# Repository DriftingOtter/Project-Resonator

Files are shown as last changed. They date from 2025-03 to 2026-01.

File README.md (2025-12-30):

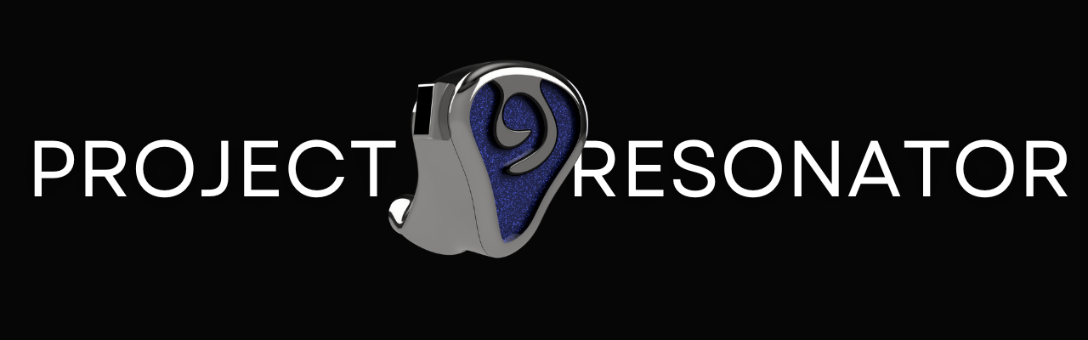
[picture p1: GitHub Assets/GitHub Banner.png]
Banner


# Project Resonator | *The* Open-Source IEM Initiative
> A love letter to the IEM/CIEM hobby.

**📖 Documentation Website:** [https://driftingotter.github.io/Project-Resonator-Web/](https://driftingotter.github.io/Project-Resonator-Web/)

---

## What is Project Resonator?

Project Resonator is a comprehensive knowledge base and resource repository for the complete design cycle and engineering development of in-ear monitors (IEMs). The project aims to bridge the gap between hobbyist curiosity and professional-grade IEM development by providing both the technical resources and educational foundation needed to understand and create high-fidelity audio devices.

### Core Resources

Project Resonator provides a complete suite of engineering resources:

- **CAD Shell Design Files** — Parametric 3D models for ergonomic IEM housings
- **Crossover Simulation Circuits** — Fully documented acoustic crossover networks in VituixCAD
- **PCB Design Files** — Production-ready circuit board layouts in KiCad format
- **Driver Characterization Data** — Frequency response and impedance measurements for balanced armature, dynamic, and electrostatic drivers

These resources are designed for both DIY enthusiasts exploring personal audio projects and aspiring entrepreneurs researching entry into the IEM market who may lack formal training in acoustics or electrical engineering.

### Educational Framework

Beyond physical assets, Project Resonator's primary value lies in its structured tutorial system that demystifies each stage of IEM development:

- **Driver Technology & Selection** — Understanding the physics and performance characteristics of transducer types
- **Crossover Circuit Design** — Acoustic filter theory and frequency division network topology
- **PCB Engineering in KiCad** — Translating schematic designs into manufacturable circuit boards
- **CAD Modeling for Acoustics** — Shell geometry, acoustic chambers, and sound bore design in Fusion 360

By consolidating these resources into a single, cohesive repository, Project Resonator enables users to understand the technology they use daily and provides a foundation for experimentation, innovation, and research & development in personal audio.

### Open-Source Collaboration

The open-source nature of this project allows the community to contribute to a centralized knowledge base, helping others in the same pursuit by:

- Improving and expanding existing documentation
- Contributing additional design files and measurement data
- Sharing novel tuning approaches and manufacturing techniques
- Building supplementary tools and resources for IEM development

Project Resonator serves as a living resource that evolves with the IEM community, fostering innovation through shared knowledge and collaborative development.

---

## The Reference Design (Template)

While the guides apply to *any* IEM project, we provide a complete set of files for a specific "Reference" model to get you started.

**Configuration:** All-BA 4-Driver (1× Low + 1× Mid + 2× High)

**Drivers:**
- Knowles CI-22955 (Low)
- Knowles BK-26824 (Mid)
- Knowles SWFK-31736 (Highs)

**Target Tuning:** Similar to the *Moondrop x Crinacle DUSK*

**Estimated Build Cost:** ~$200-300

### Reference Crossover Diagram

```mermaid
graph LR
    Input[Source Input] --> Woofer_Path[Woofer Path<br/>CI-22955]
    Input --> Mid_Path[Mid Path<br/>BK-26824]
    Input --> High_Path[High Path<br/>SWFK-31736]
    
    Woofer_Path --> R1[22Ω Series]
    R1 --> C1[4.7µF Parallel]
    C1 --> Woofer[CI-22955<br/>BA Woofer]
    
    Mid_Path --> C2[10µF Series]
    C2 --> R2[22Ω Series]
    R2 --> C3[4.7µF Parallel]
    C3 --> Mids[BK-26824<br/>BA Mids]
    
    High_Path --> T1_Path[Tweeter 1]
    High_Path --> T2_Path[Tweeter 2]
    
    T1_Path --> C4[2.2µF Series]
    C4 --> R3[6.8Ω Parallel]
    R3 --> Tweeter1[SWFK-31736<br/>Unit A]
    
    T2_Path --> C5[2.2µF Series]
    C5 --> R4[22Ω Parallel]
    R4 --> Tweeter2[SWFK-31736<br/>Unit B]
    
    style Woofer fill:#1a1a1a
    style Mids fill:#1a1a1a
    style Tweeter1 fill:#1a1a1a
    style Tweeter2 fill:#1a1a1a
    style Input fill:#1a1a1a
```

**Note:** The reference tuning is highly individualized. The project's purpose is to provide all necessary tools and resources pre-configured, allowing you to use this as a foundation to tune and create an IEM tailored to your preferences.

---

## 🔧 Technologies Used & Software Required

1. **VituixCAD** — Tuning simulation and acoustic crossover design
2. **KiCad** — Schematic and PCB design
3. **Autodesk Fusion 360** — CAD modeling for IEM shells
4. **FPGraphTracer** — Extracting frequency and impedance responses from driver spec sheets

**Additional Resources:**
- [YouTube Playlist: IEM Building Resources](https://youtube.com/playlist?list=PL4ahDGGN5zBFhmGqVUoBdOnjuF_9HXV5L)
- [Full Documentation Website](https://driftingotter.github.io/Project-Resonator-Web/)

---

## 🛠️ Installation & Setup Guide

### VituixCAD Setup

1. Download VituixCAD from [https://kimmosaunisto.net/](https://kimmosaunisto.net/)
2. Install and open the `.vxp` simulation file included in this repository
3. **Fix missing file paths:**
   - You'll likely see "missing file path" errors on first load
   - Click the folder icon next to each `.frd` or `.zma` file slot
   - Navigate to the `BA Driver Spec Sheets` folder in this repo
   - Re-link the appropriate files for each driver

*(This only needs to be done once per project file)*

### Downloading IEM Shell Files

All IEM shell files are hosted externally on **MEGA** due to GitHub's file size limitations.

🔗 **[Download Shell Files from MEGA](https://mega.nz/folder/2Z4WzYDR#g-NULd1YQFsHa81YXLZzIw)**

The archive includes:
- **Ready-To-Print** — `.stl` files for direct 3D printing
- **Fusion-Shell-Models** — Editable `.f3d` files for customization in Fusion 360

---

## 📚 Documentation

Complete guides are available on the [Project Resonator Documentation Website](https://driftingotter.github.io/Project-Resonator-Web/), including:

### Engineering & Design
- [Driver Selection](https://driftingotter.github.io/Project-Resonator-Web/docs/Driver-Selection)
- [Crossover Design](https://driftingotter.github.io/Project-Resonator-Web/docs/Crossover-Design)
- [Crossover Tuning](https://driftingotter.github.io/Project-Resonator-Web/docs/Crossover-Tuning)
- [Component Picking](https://driftingotter.github.io/Project-Resonator-Web/docs/Component-Picking)

### Manufacturing & CAD
- [PCB Design](https://driftingotter.github.io/Project-Resonator-Web/docs/PCB-Design)
- [Shell Design](https://driftingotter.github.io/Project-Resonator-Web/docs/Shell-Design)
- [Shell Material and Manufacturing](https://driftingotter.github.io/Project-Resonator-Web/docs/Shell-Material-and-Manufacturing)

### Project Information
- [Tools & Software](https://driftingotter.github.io/Project-Resonator-Web/docs/Tools-&-Software)
- [Project Goals & Philosophy](https://driftingotter.github.io/Project-Resonator-Web/docs/Project-Goals-Philosophy)
- [Project Licensing and Usage](https://driftingotter.github.io/Project-Resonator-Web/docs/Project-Licensing-and-Usage)
- [FAQ & Troubleshooting](https://driftingotter.github.io/Project-Resonator-Web/docs/FAQ-Troubleshooting)
- [How to Contribute](https://driftingotter.github.io/Project-Resonator-Web/docs/Contribution)

---

## ❓ Can I Use These Files To Build My Own IEM?

**Absolutely.** This project is licensed under **CERN-OHL-W** (weakly reciprocal), which allows you to:

- Build IEMs for personal use
- Modify and improve the designs
- Use this as a foundation for commercial projects

The license maintains the open-source spirit while being permissive enough for commercial applications. For full details, see the [Project Licensing and Usage](https://driftingotter.github.io/Project-Resonator-Web/docs/Project-Licensing-and-Usage) documentation.

**Note:** This design represents a learning journey and is far from perfect—but it provides a solid foundation and realistic look at what an IEM build process entails. Use it as a starting point to avoid some of the mistakes made along the way.

---

## 🤝 Contributing

Project Resonator welcomes contributions from the community! Whether you're improving documentation, adding measurement data, sharing tuning variants, or fixing errors, your input helps everyone.

See the [Contribution Guide](https://driftingotter.github.io/Project-Resonator-Web/docs/Contribution) for details on how to get involved.

---

## 🚧 Current Status & Community Testing

**Important:** The reference design has not yet been physically tested by the project author due to budget constraints (~$300 build cost). If you build this design, your feedback and measurements would be invaluable to the community. Please share your results and listening impressions!

---

## 👨‍💻 Author

**Daksh Kaul** (DriftingOtter)

---

## 🙌 Credits & Acknowledgments

Special thanks to:

- **Head-Fi DIY IEM Community** — For fostering knowledge sharing and experimentation
- **[Kozh](https://www.youtube.com/@kozh4013/videos)** — IEM design tutorials and insights
- **[Kirby Meets Audio](https://youtu.be/QClvPIuW3zI)** — Driver selection and acoustic theory
- **[Crinacle](https://www.youtube.com/watch?v=tCqV3ZRcZ9g)** — Measurement methodology and target curves
- **[Mr.T's Design Graveyard](https://youtu.be/3FGNw28xBr0)** — PCB design techniques

*If I've forgotten to credit you, please reach out—contributions are always acknowledged.*

---

## 📄 License

This project is licensed under **CERN Open Hardware Licence Version 2 - Weakly Reciprocal** (CERN-OHL-W).

See [LICENSE](./LICENSE) or the [Project Licensing Documentation](https://driftingotter.github.io/Project-Resonator-Web/docs/Project-Licensing-and-Usage) for full details.

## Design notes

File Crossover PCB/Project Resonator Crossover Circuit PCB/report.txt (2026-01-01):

Warning: Width correction constrained.  The width correction value must be in the range of [0.000001 mm; -0.000002 mm] for the current design rules.
Warning: Width correction constrained.  The width correction value must be in the range of [0.000001 mm; -0.000002 mm] for the current design rules.
Plotted to '/Users/daksh/Documents/Project-Resonator/Crossover PCB/Project Resonator Crossover Circuit PCB/Project Resonator Crossover Circuit PCB/Project Resonator Crossover Circuit PCB-F_Cu.gbr'.
Plotted to '/Users/daksh/Documents/Project-Resonator/Crossover PCB/Project Resonator Crossover Circuit PCB/Project Resonator Crossover Circuit PCB/Project Resonator Crossover Circuit PCB-B_Cu.gbr'.
Plotted to '/Users/daksh/Documents/Project-Resonator/Crossover PCB/Project Resonator Crossover Circuit PCB/Project Resonator Crossover Circuit PCB/Project Resonator Crossover Circuit PCB-F_Paste.gbr'.
Plotted to '/Users/daksh/Documents/Project-Resonator/Crossover PCB/Project Resonator Crossover Circuit PCB/Project Resonator Crossover Circuit PCB/Project Resonator Crossover Circuit PCB-B_Paste.gbr'.
Plotted to '/Users/daksh/Documents/Project-Resonator/Crossover PCB/Project Resonator Crossover Circuit PCB/Project Resonator Crossover Circuit PCB/Project Resonator Crossover Circuit PCB-F_Silkscreen.gbr'.
Plotted to '/Users/daksh/Documents/Project-Resonator/Crossover PCB/Project Resonator Crossover Circuit PCB/Project Resonator Crossover Circuit PCB/Project Resonator Crossover Circuit PCB-B_Silkscreen.gbr'.
Plotted to '/Users/daksh/Documents/Project-Resonator/Crossover PCB/Project Resonator Crossover Circuit PCB/Project Resonator Crossover Circuit PCB/Project Resonator Crossover Circuit PCB-F_Mask.gbr'.
Plotted to '/Users/daksh/Documents/Project-Resonator/Crossover PCB/Project Resonator Crossover Circuit PCB/Project Resonator Crossover Circuit PCB/Project Resonator Crossover Circuit PCB-B_Mask.gbr'.
Plotted to '/Users/daksh/Documents/Project-Resonator/Crossover PCB/Project Resonator Crossover Circuit PCB/Project Resonator Crossover Circuit PCB/Project Resonator Crossover Circuit PCB-Edge_Cuts.gbr'.
Created Gerber job file '/Users/daksh/Documents/Project-Resonator/Crossover PCB/Project Resonator Crossover Circuit PCB/Project Resonator Crossover Circuit PCB/Project Resonator Crossover Circuit PCB-job.gbrjob'.
Info: Done.
Info: Done.

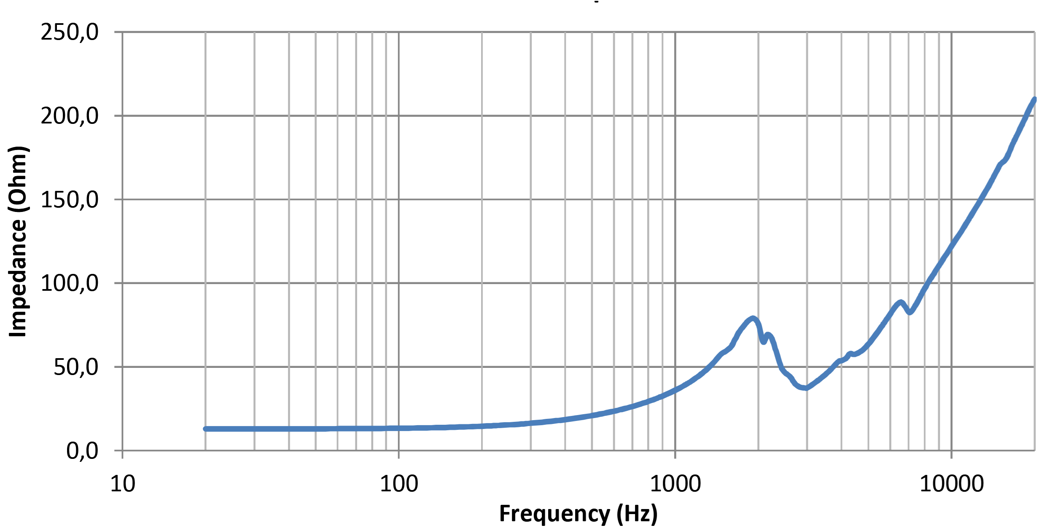
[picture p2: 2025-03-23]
BA Driver Spec Sheets/Knowles_ED_30262/Impedence_Response.png

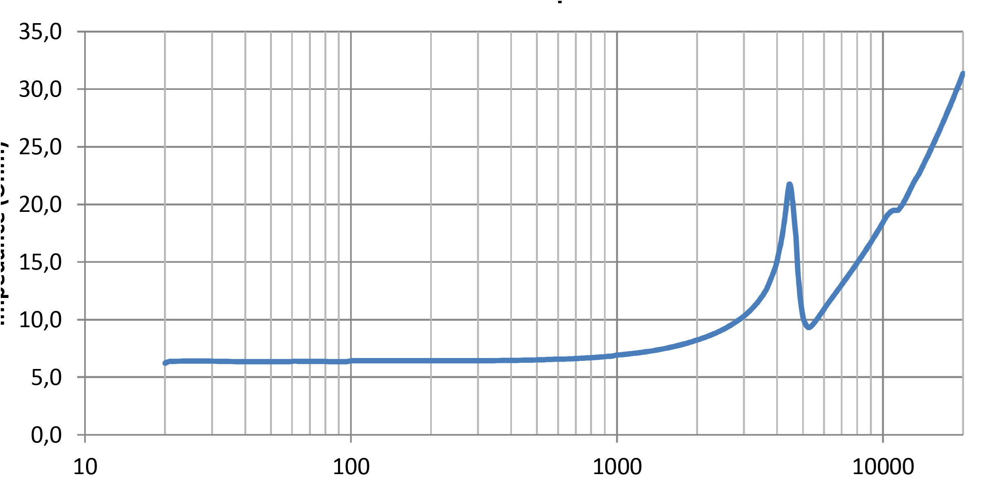
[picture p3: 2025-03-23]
BA Driver Spec Sheets/Knowles_SWFK_31736/Impedence_Response.png

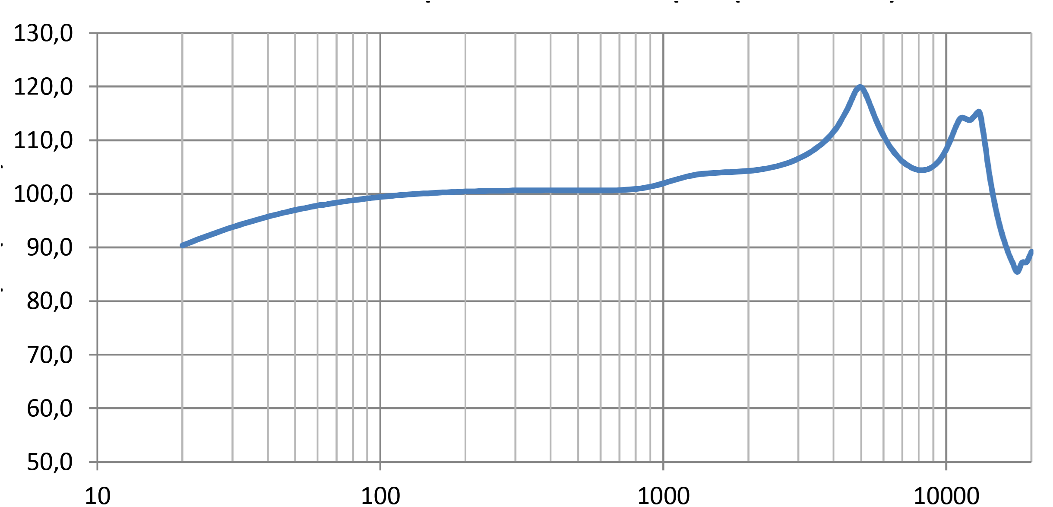
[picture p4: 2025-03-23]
BA Driver Spec Sheets/Knowles_SWFK_31736/Frequnecy_Response.png

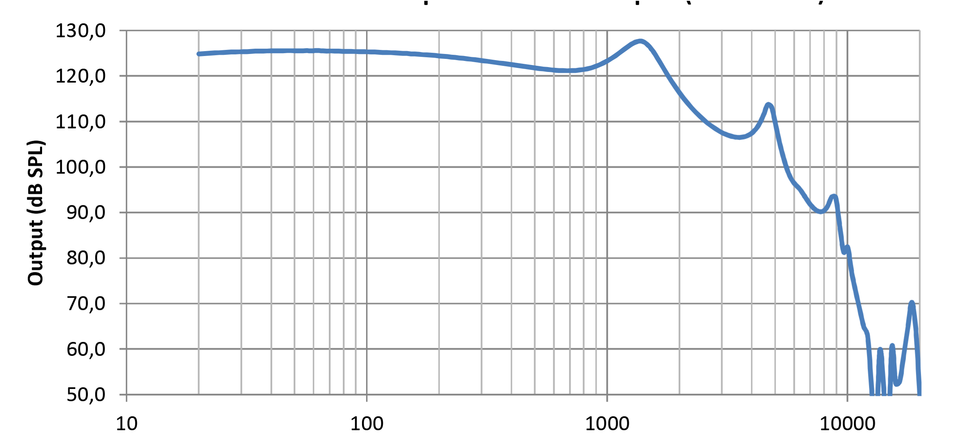
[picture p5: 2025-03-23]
BA Driver Spec Sheets/Knowles_HODVTEC-31618/Frequnecy_Response.png

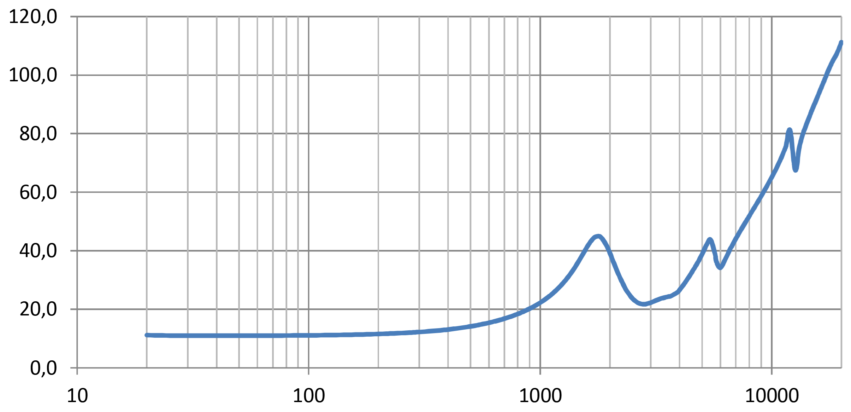
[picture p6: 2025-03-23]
BA Driver Spec Sheets/Knowles_BK_26824/Impedence_Response.png

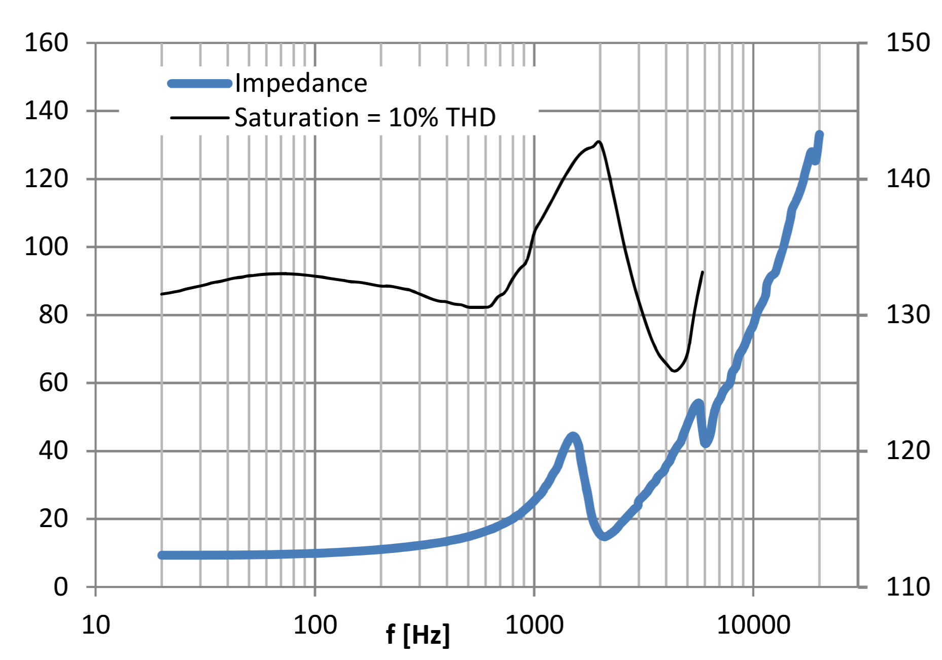
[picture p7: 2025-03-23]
BA Driver Spec Sheets/Knowles_RDI_34006/Impedence_Response.png

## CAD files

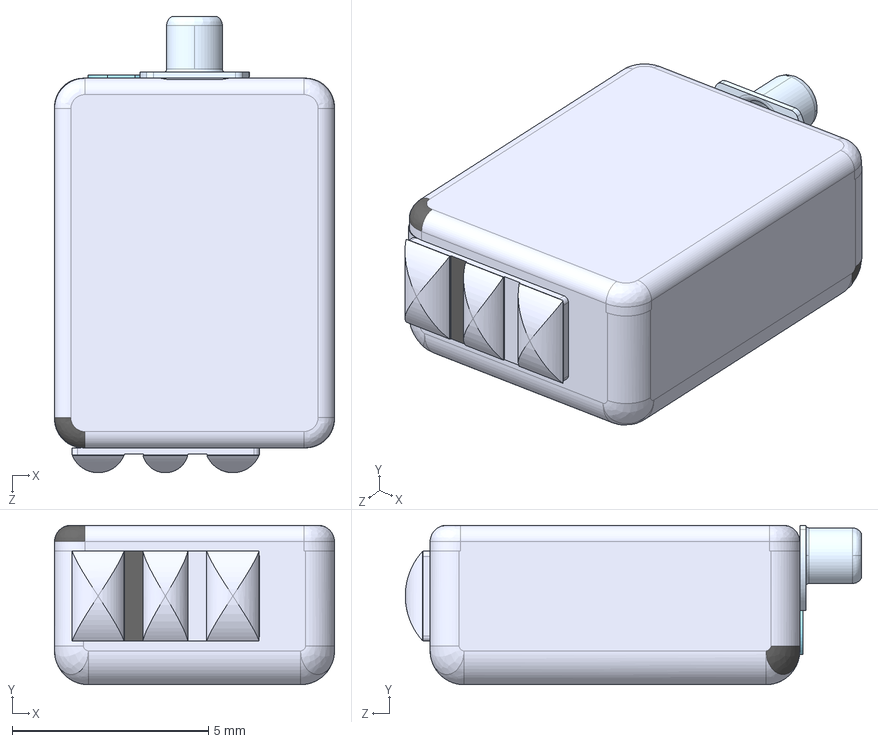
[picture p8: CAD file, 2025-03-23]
BA Driver Spec Sheets/Knowles_CI_22955/LIB_CI-22955-000/CI-22955-000/3D/CI-22955-000.stp
7.14 x 4.06 x 11.6 mm
ci-22955-000_sw1
ci-22955-000_sw2
ci-22955-000_sw3
ci-22955-000_sw4
ci-22955-000_sw5

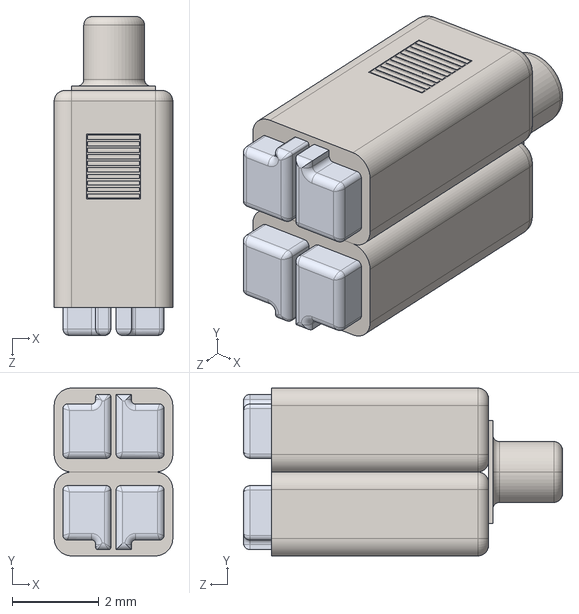
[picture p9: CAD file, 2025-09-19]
BA Driver Spec Sheets/Knowles_SWFK_31736/LIB_SWFK-31736-000/SWFK-31736-000/3D/SWFK-31736-000.stp
2.73 x 3.86 x 7.34 mm

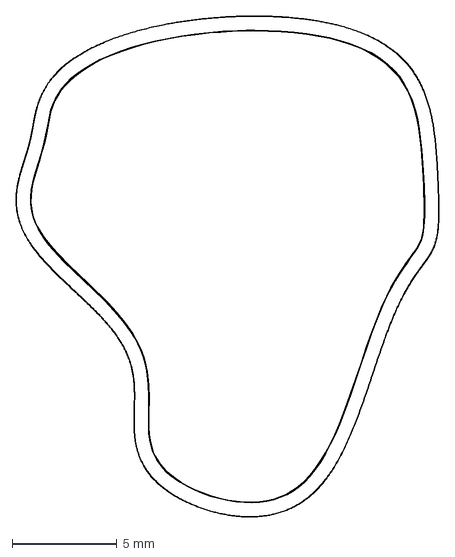
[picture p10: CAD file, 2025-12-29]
Crossover PCB/Entangler_TWS/Entangle_PCB_Outline.dxf
20.2 x 23.9 mm

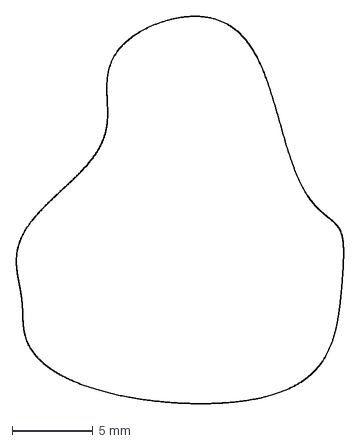
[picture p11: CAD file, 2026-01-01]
Crossover PCB/PCB OUTLINE.dxf
20.2 x 23.9 mm

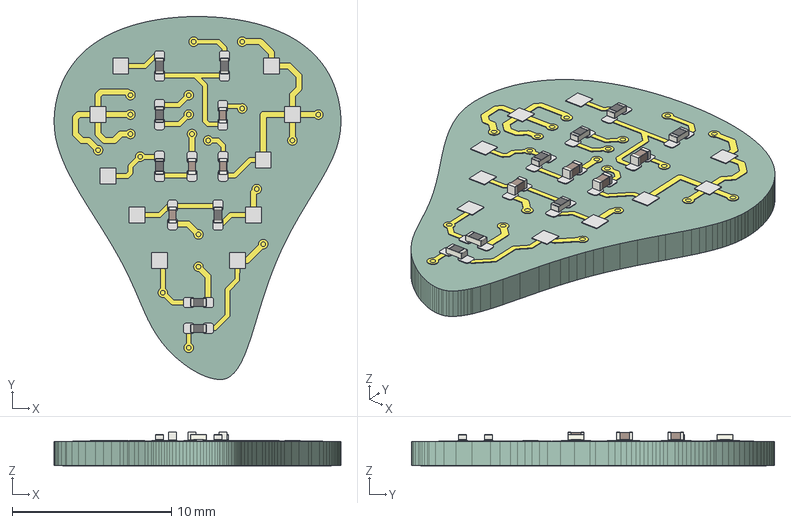
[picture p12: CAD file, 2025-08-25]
Crossover PCB/Project Resonator Crossover Circuit PCB.step
18.0 x 22.8 x 2.13 mm
R_0402_1005Metric x 7
C_0402_1005Metric x 4
Project Resonator Crossover Circuit PCB_copper
Project Resonator Crossover Circuit PCB_pad
Project Resonator Crossover Circuit PCB_via
Project Resonator Crossover Circuit PCB_PCB

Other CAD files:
BA Driver Spec Sheets/Knowles_SWFK_31736/LIB_SWFK-31736-000/SWFK-31736-000/3D/SWFK-31736-000.obj

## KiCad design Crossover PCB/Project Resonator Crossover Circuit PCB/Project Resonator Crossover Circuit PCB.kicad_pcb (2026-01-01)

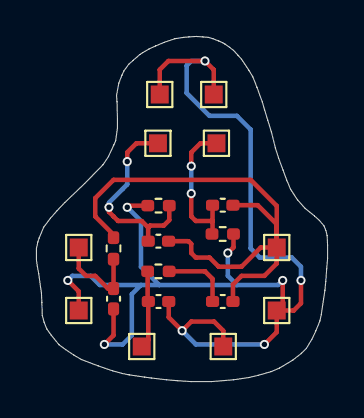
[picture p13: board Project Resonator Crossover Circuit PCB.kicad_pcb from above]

Board: 2 copper layers, 16.2 x 19.2 mm, 19 parts (0 on the bottom side), 2 nets.

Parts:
C1: 10uF; C_0402_1005Metric_Pad0.74x0.62mm_HandSolder
C2, C6: 2.2uF; C_0402_1005Metric_Pad0.74x0.62mm_HandSolder
C4: 0.10uF; C_0402_1005Metric_Pad0.74x0.62mm_HandSolder
C5: 4.7uF; C_0402_1005Metric_Pad0.74x0.62mm_HandSolder
H1: CI PAD (+); TestPoint_Pad_1.0x1.0mm
H2: CI PAD (-); TestPoint_Pad_1.0x1.0mm
H3: BK PAD (+); TestPoint_Pad_1.0x1.0mm
H4: BK PAD (-); TestPoint_Pad_1.0x1.0mm
H5: SWFK #1 PAD (+); TestPoint_Pad_1.0x1.0mm
H6: SWFK #1 PAD (-); TestPoint_Pad_1.0x1.0mm
H7: SWFK #2 PAD (+); TestPoint_Pad_1.0x1.0mm
H8: SWFK #2 PAD (-); TestPoint_Pad_1.0x1.0mm
H9: SOURCE PAD (+); TestPoint_Pad_1.0x1.0mm
H10: SOURCE PAD (-); TestPoint_Pad_1.0x1.0mm
R2, R5, R6: 22R; R_0402_1005Metric_Pad0.72x0.64mm_HandSolder
R3: 6.8R; R_0402_1005Metric_Pad0.72x0.64mm_HandSolder

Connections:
+: C1.1, C2.1, C2.2, C4.1, C4.2, C5.1, C6.1, C6.2, H1.1, H3.1, H5.1, H7.1, H9.1, R2.1, R2.2, R3.1, R5.1, R5.2, R6.1
GND: C1.2, C5.2, H2.1, H4.1, H6.1, H8.1, H10.1, R3.2, R6.2

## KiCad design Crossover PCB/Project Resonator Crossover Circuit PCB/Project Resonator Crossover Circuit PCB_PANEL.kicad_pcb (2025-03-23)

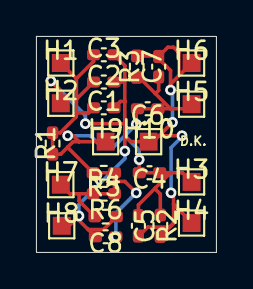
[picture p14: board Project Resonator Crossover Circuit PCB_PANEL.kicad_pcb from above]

Board: 2 copper layers, 10.0 x 12.0 mm, 24 parts (0 on the bottom side), 2 nets.

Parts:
C1, C2, C3: 100u; C_0402_1005Metric_Pad0.74x0.62mm_HandSolder
C4: 0.027u; C_0402_1005Metric_Pad0.74x0.62mm_HandSolder
C5: 4.7u; C_0402_1005Metric_Pad0.74x0.62mm_HandSolder
C6: 0.008u; C_0402_1005Metric_Pad0.74x0.62mm_HandSolder
C7: 2.2u; C_0402_1005Metric_Pad0.74x0.62mm_HandSolder
C8: 10u; C_0402_1005Metric_Pad0.74x0.62mm_HandSolder
H1, H3, H5, H7, H9: + MountingHole_Pad; TestPoint_Pad_1.0x1.0mm
H2, H4, H6, H8: - MountingHole_Pad; TestPoint_Pad_1.0x1.0mm
H10: MountingHole_Pad; TestPoint_Pad_1.0x1.0mm
R1: 5600R; R_0402_1005Metric_Pad0.72x0.64mm_HandSolder
R2: 22R; R_0402_1005Metric_Pad0.72x0.64mm_HandSolder
R3: 10000R; R_0402_1005Metric_Pad0.72x0.64mm_HandSolder
R4: 6800R; R_0402_1005Metric_Pad0.72x0.64mm_HandSolder
R5: 0.092R; R_0402_1005Metric_Pad0.72x0.64mm_HandSolder
R6: 6.8R; R_0402_1005Metric_Pad0.72x0.64mm_HandSolder

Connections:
+: C1.1, C2.1, C3.1, C4.1, C4.2, C5.1, C6.1, C6.2, C7.1, C8.1, H1.1, H3.1, H5.1, H7.1, H9.1, R1.1, R1.2, R2.1, R3.1, R4.1, R4.2, R5.1, R5.2, R6.1
GND: C1.2, C2.2, C3.2, C5.2, C7.2, C8.2, R2.2, R3.2, R6.2

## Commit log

2025-03-23 my passion project
    [CI-22955-000.stp, DigiKey_PCB_Components_Parts_List.csv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]
2025-03-23 removed software files, and old files not used for project
    [CI-22955-000.stp]
2025-03-23 Accdentally removed BA driver measurements
    [CI-22955-000.stp]
2025-03-27 modified crossover to use 2nd order low pass instead of high capacitance series chains
2025-04-04 MAJOR UPDATE: Improved Crossover to reduce redudent componets from 15 -> 10, Improved subbass isolation, updated PCB to reflect changes, added v3 shell images to assets, uploaded new gerber and drill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
    [Project Resonator Crossover Circuit PCB-B_Cu.gbr, Project Resonator Crossover Circuit PCB-B_Mask.gbr, Project Resonator Crossover Circuit PCB-B_Silkscreen.gbr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]
2025-04-04 Updated README to include Morten Arnoldus's measurements for Knowles BA drivers && included files to the BA drivers measurements directory
2025-04-04 Added the compressed Gerber and Drill Files of the new PCB overall
2025-04-04 updated PCB to connect ground pour to GND and make track size to 8mils and fixed clearence issues
    [Project Resonator Crossover Circuit PCB-B_Cu.gbr, Project Resonator Crossover Circuit PCB-B_Mask.gbr, Project Resonator Crossover Circuit PCB-B_Paste.gbr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]
2025-04-04 updated crossover to have ~5-6db cut at 10k to match shell material high frequency resonace (updated CROSSOVER, SCHEMATIC, PCB, GERBER, and DRILL FILES
    [Project Resonator Crossover Circuit PCB-B_Cu.gbr, Project Resonator Crossover Circuit PCB-B_Mask.gbr, Project Resonator Crossover Circuit PCB-B_Paste.gbr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]
2025-04-04 forgot to add the compressed .zip for the high frequnecy cut
2025-04-08 updated 800ohm to 750ohm for product resistor in use from JLCPCB, updated ground and added 1 more resistor for CI driver, updated gerber and drill files and updated crossover ciruit to match changes
    [Project Resonator Crossover Circuit PCB-B_Mask.gbr, Project Resonator Crossover Circuit PCB-B_Silkscreen.gbr, Project Resonator Crossover Circuit PCB-CuBottom.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]
2025-04-24 Added Mermaid Diagram Of Crossover Circuit
2025-04-24 Moved Diagram to README and fixed some mispellings and created common positive and ground
2025-08-25 Redesigned Layout of PCB to Wrap Shell, Updated Overall Shell Design, Removed Bluetooth Code experimental, Rendered New colorways mockups
    [CROSSOVER PCB MODEL.step, PCB OUTLINE.dxf, Project Resonator Crossover Circuit PCB.kicad_pcb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]
2025-09-15 moved to latest version of vituixCAD and ported crossover files, and moved old version to legacy directory, and also removed SMD componenet list directory due to deprecation
    [DigiKey_PCB_Components_Parts_List.csv]
2025-09-19 updated crossover to fit purchased components assortment (minor tweaks, almost exactly the same), and added SWFK 3D model
    [SWFK-31736-000.obj, SWFK-31736-000.stp]
2025-09-19 Updated crossover diagram to set labels to drivers correctly from sub-to-air, and updated crossover capacitance and resistance values
2025-10-22 updated crossover circuit and moved old crossover to legacy folder
2025-12-29 added wiki image assets for shell guide
    [Entangle_PCB_Outline.dxf, Entangler.kicad_pcb, Entangler.kicad_sch]
2025-12-29 Delete wiki_assets/Screenshot 2025-12-28 at 10.53.08 PM.png (driver cutout extortion image)
    wasn't showing the actual red extrusion zone
2026-01-01 updated PCB crossover to match the latest crossover diagram and fixed size to fit latest version of the shell
    [CROSSOVER PCB MODEL.step, PCB OUTLINE.dxf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]
2026-01-01 downloaded updated drill files
